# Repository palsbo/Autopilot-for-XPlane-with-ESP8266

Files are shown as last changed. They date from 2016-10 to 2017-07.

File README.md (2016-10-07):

# Autopilot
An ESP8266 based Autopilot for X-Plane
This is a hardware based autopilot to be useed together with X-Plane (tested on X-Plane v10.50).

Hardware:
The printed circuit is developed in Target3001
OBS! read the file 'corrections.txt' before mounting the printed curcuit.

Software:
The software for the ESP8266 is in the Arduino folder together with all required libraries.
(for Arduino IDE)

Project details here: http://palsbo.com/xplane/Autopilot.html 

Files in this GitHup are the newest

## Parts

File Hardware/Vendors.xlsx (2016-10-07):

Conmonent | Value | Description | Vendor URL | prod code
R10 | 7x3K3 | Resistor network | http://dk.rs-online.com/ | 4608x-101-332lf
R11 - R12 | 7x330 | Resistor network | http://dk.rs-online.com/ | 4608x-101-331lf
R8 | 10K | Trim Pot | http://dk.rs-online.com/ | 3362P-1-103LF
C1 - C3 | 100nf | poly cond. | http://dk.rs-online.com/ | bfc236845104
SD1 - SD12 |  | Switch with led | http://www.velleman.eu/products/view/?id=2757 | SP86-B2-5-1
PE1 - PE3 | MC23017 | I2C port expander | https://www.adafruit.com/product/732
Display1 | LCD | 20x4 LCD | https://www.sparkfun.com/products/256
IC2 | ESP8266-01 | WiFi proc. | https://www.sparkfun.com/products/13678
J1 | 5V | powerplug | http://dk.rs-online.com/ | FC68146SP
Box |  | Alubox | http://www.eluxson.se/apparatlador-aluminium/1568-ah-102-sw.html | AH-102/SW

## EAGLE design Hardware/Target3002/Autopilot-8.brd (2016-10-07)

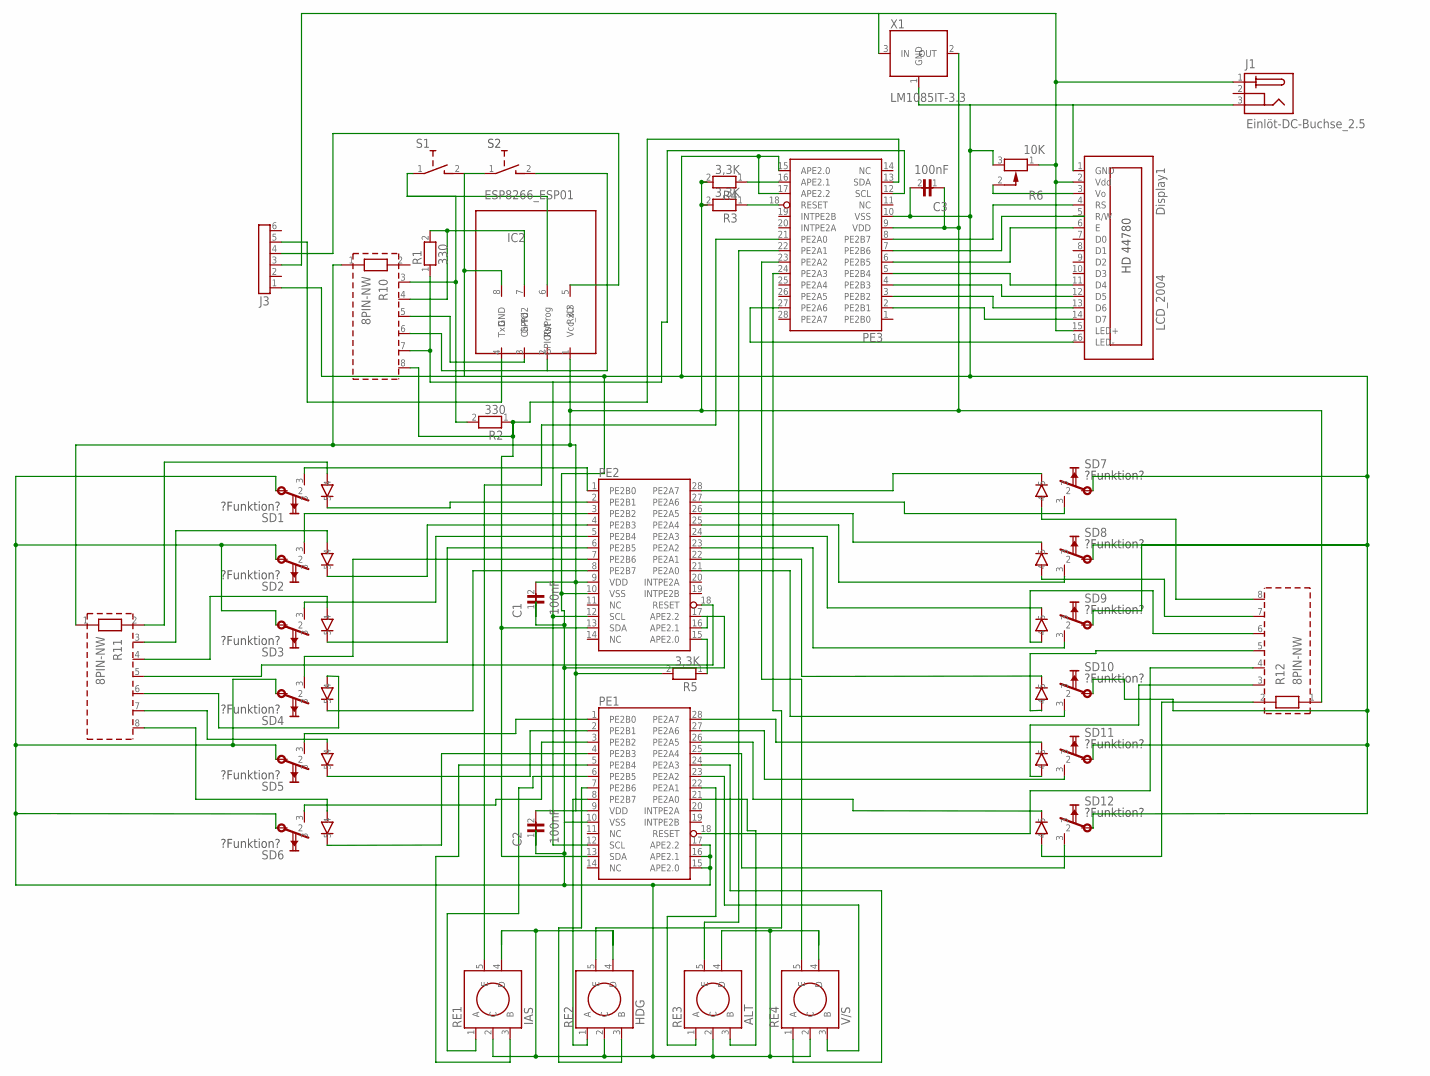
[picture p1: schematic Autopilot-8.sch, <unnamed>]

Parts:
C1: 100nF; 4X13R10,16_11
C2: 100nF; 4X13R10,16_12
C3: 100nF; 4X13R10,16_15
Display1: LCD_2004; LCD2004_13
IC2: ESP8266_ESP01; ESP01_6
J1: Einlöt-DC-Buchse_2.5; EINLÖT-DC-BUCHSE_2.5MM_36
J3: PinHeader_1x06_W_2,54; 1X06-90_32
PE1: PORTEXPANDER MCP23017; PortExpander_Gehäuse:PDIP-28_4
PE2: PORTEXPANDER MCP23017; PortExpander_Gehäuse:PDIP-28_5
PE3: PORTEXPANDER MCP23017; PortExpander_Gehäuse:PDIP-28_14
R1: 330; 0207_7
R2: 330; 0207_8
R3: 3,3K; 0207_17
R4: 3,3K; 0207_18
R5: 3,3K; 0207_19
R6: 10K; POTI_PD84_35
R10: 8PIN-NW; SIL8_16
R11: 8PIN-NW; SIL8_9
R12: 8PIN-NW; SIL8_10
RE1: IAS; STEC12E08_3
RE2: HDG; STEC12E08_2
RE3: ALT; STEC12E08_1
RE4: V/S; STEC12E08_0
S1: PHAP3362A; KURZHUBTASTER_DURCHSTECKMONT._33
S2: PHAP3362A; KURZHUBTASTER_DURCHSTECKMONT._34
SD1: TASTER_DIGITAST_STD-LED-SJS; TASTER_DIGITAST_STD(#1)(#1)_20
SD2: TASTER_DIGITAST_STD-LED-SJS; TASTER_DIGITAST_STD(#1)(#1)_21
SD3: TASTER_DIGITAST_STD-LED-SJS; TASTER_DIGITAST_STD(#1)(#1)_22
SD4: TASTER_DIGITAST_STD-LED-SJS; TASTER_DIGITAST_STD(#1)(#1)_23
SD5: TASTER_DIGITAST_STD-LED-SJS; TASTER_DIGITAST_STD(#1)(#1)_24
SD6: TASTER_DIGITAST_STD-LED-SJS; TASTER_DIGITAST_STD(#1)(#1)_25
SD7: TASTER_DIGITAST_STD-LED-SJS; TASTER_DIGITAST_STD(#1)(#1)_26
SD8: TASTER_DIGITAST_STD-LED-SJS; TASTER_DIGITAST_STD(#1)(#1)_27
SD9: TASTER_DIGITAST_STD-LED-SJS; TASTER_DIGITAST_STD(#1)(#1)_28
SD10: TASTER_DIGITAST_STD-LED-SJS; TASTER_DIGITAST_STD(#1)(#1)_29
SD11: TASTER_DIGITAST_STD-LED-SJS; TASTER_DIGITAST_STD(#1)(#1)_30
SD12: TASTER_DIGITAST_STD-LED-SJS; TASTER_DIGITAST_STD(#1)(#1)_31
X1: LM1085IT-3.3; TO220_37

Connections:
5V: Display1.2 (Vdd), Display1.15 (LED+), J1.1 (S), J3.3, R6.1, X1.3 (IN)
ALT: PE2.23 (PE2A2), SD9.3
AP-AUTO: PE2.5 (PE2B4), SD3.3
AP-OFF: PE2.1 (PE2B0), SD1.3
AP-ON: PE2.3 (PE2B2), SD2.3
APE2.0: PE2.15 (APE2.0), R5.1
ATHR: PE1.1 (PE2B0), SD5.3
B: PE1.23 (PE2A2), RE4.3 (B)
BC: PE1.25 (PE2A4), SD12.3
D4: Display1.11 (D4), PE3.5 (PE2B4)
D6: Display1.13 (D6), PE3.3 (PE2B2)
ESP-RST: IC2.2 (Rst), R10.6, S2.2
FLCH: PE2.7 (PE2B6), SD4.3
GND: C1.1, C2.1, C3.2, Display1.1 (GND), IC2.8 (GND), J1.3 (T), J3.1, PE1.10 (VSS), PE1.15 (APE2.0), PE1.16 (APE2.1), PE1.17 (APE2.2), PE2.10 (VSS), PE2.16 (APE2.1), PE2.17 (APE2.2), PE3.10 (VSS), PE3.15 (APE2.0), PE3.17 (APE2.2), R6.3, RE1.2 (C), RE1.4 (D), RE2.2 (C), RE2.4 (D), RE3.2 (C), RE3.4 (D), RE4.2 (C), RE4.4 (D), S1.2, S2.1, SD1.2, SD2.2, SD3.2, SD4.2, SD5.2, SD6.2, SD7.2, SD8.2, SD9.2, SD10.2, SD11.2, SD12.2, X1.1 (GND)
GPIO0/Prog: IC2.6 (GPIO0/Prog), R2.2, R10.3, S1.1
GPIO2: IC2.7 (GPIO2), R1.2, R10.4
GS: PE2.21 (PE2A0), SD10.3
HDG: PE2.27 (PE2A6), SD7.3
LED-ALT: PE2.24 (PE2A3), SD9.4
LED-AP-AUTP: PE2.6 (PE2B5), SD3.4
LED-AP-OFF: PE2.2 (PE2B1), SD1.4
LED-AP-ON: PE2.4 (PE2B3), SD2.4
LED-ATHR: PE1.2 (PE2B1), SD5.4
LED-BC: PE1.26 (PE2A5), SD12.4
LED-FLCH: PE2.8 (PE2B7), SD4.4
LED-GS: PE2.22 (PE2A1), SD10.4
LED-HDG: PE2.28 (PE2A7), SD7.4
LED-LOC: PE1.4 (PE2B3), SD6.4
LED-VNAV: PE2.26 (PE2A5), SD8.4
LED-VS: PE1.28 (PE2A7), SD11.4
LOC: PE1.3 (PE2B2), SD6.3
PE2A1: PE1.22 (PE2A1), RE3.1 (A)
PE2B4: PE1.5 (PE2B4), RE1.3 (B)
PE2B5: Display1.12 (D5), PE3.4 (PE2B3)
PE2B6: PE1.7 (PE2B6), RE2.3 (B)
R/W: Display1.5 (R/W), PE3.7 (PE2B6)
RESET: PE1.18 (RESET), R12.4
RS: Display1.4 (RS), PE3.8 (PE2B7)
SCL: PE1.12 (SCL), PE2.12 (SCL), PE3.12 (SCL), R1.1, R10.7
SDA: PE1.13 (SDA), PE2.13 (SDA), PE3.13 (SDA), R2.1, R10.8
Sig$24: PE1.21 (PE2A0), RE3.3 (B)
Sig$27: PE1.8 (PE2B7), RE2.1 (A)
Sig$29: PE1.6 (PE2B5), RE1.1 (A)
Sig$107: R12.2, SD12.5
Sig$108: R12.7, SD8.5
Sig$118: IC2.3 (Ch-Pd), R10.5
Sig$129: R12.3, SD11.5
Sig$131: R12.6, SD9.5
Sig$132: R12.8, SD7.5
Sig$137: R11.2, SD1.5
Sig$138: R11.3, SD2.5
Sig$139: R11.4, SD3.5
Sig$140: PE2.18 (RESET), R11.5
Sig$141: R11.6, SD4.5
Sig$142: R11.7, SD5.5
Sig$143: R11.8, SD6.5
Sig$195: Display1.14 (D7), PE3.2 (PE2B1)
Sig$208: Display1.6 (E), PE3.6 (PE2B5)
Sig$209: PE3.18 (RESET), R3.1
Sig$211: PE3.16 (APE2.1), R4.1
Sig$230: R12.5, SD10.5
Sig$260: Display1.16 (LED-), PE3.27 (PE2A6)
Sig$269: IC2.5 (RxD), J3.4
TxD: IC2.4 (TxD), J3.5
VCC3.3: C1.2, C2.2, C3.1, IC2.1 (Vcc_3.3), PE1.9 (VDD), PE2.9 (VDD), PE3.9 (VDD), R3.2, R4.2, R5.2, R10.1, R11.1, R12.1, X1.2 (OUT)
VNAV: PE2.25 (PE2A4), SD8.3
VS: PE1.27 (PE2A6), SD11.3
Vo: Display1.3 (Vo), R6.2
ss0: PE3.21 (PE2A0), RE1.5 (E)
ss1: PE3.22 (PE2A1), RE3.5 (E)
ss2: PE3.23 (PE2A2), RE4.5 (E)
ss3: PE3.24 (PE2A3), RE2.5 (E)
xx: PE1.24 (PE2A3), RE4.1 (A)

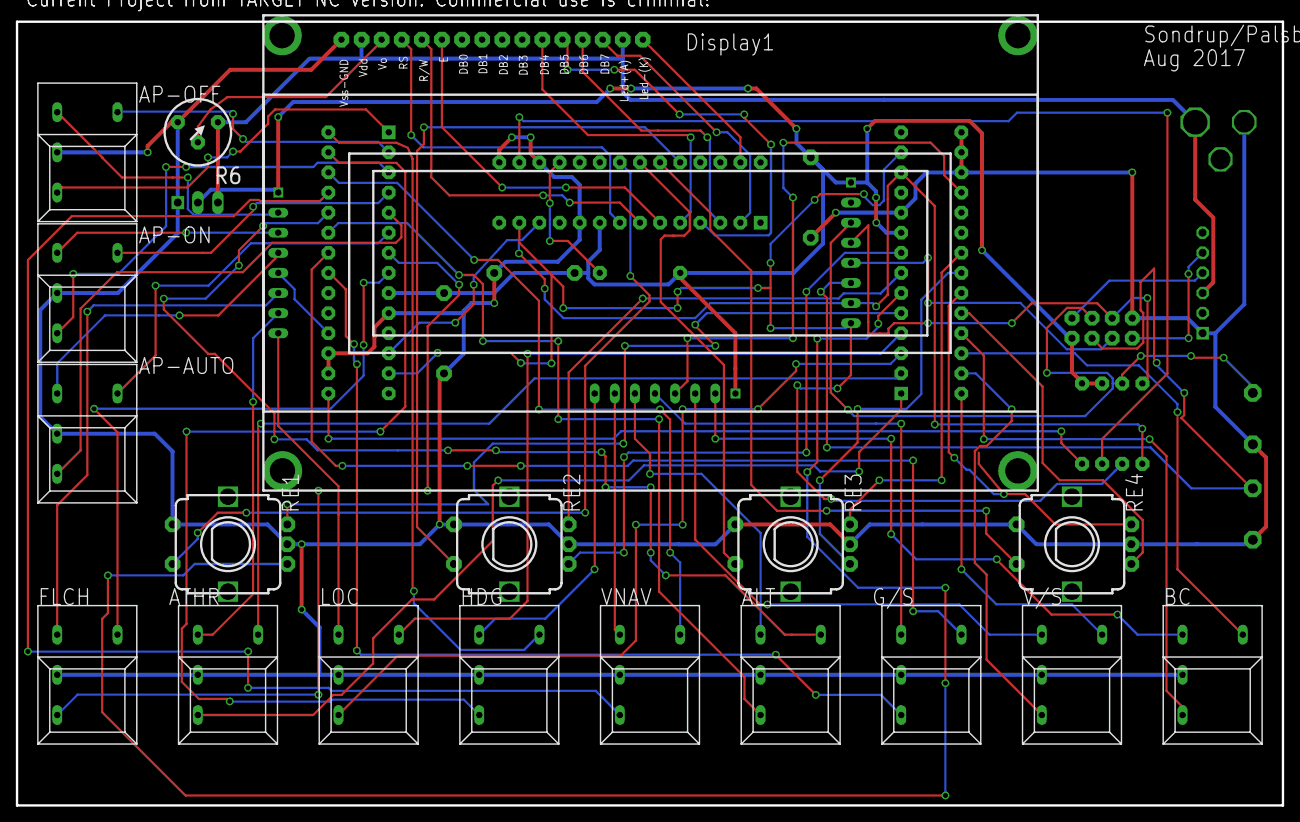
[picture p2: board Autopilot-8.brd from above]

Board: 2 copper layers, 160.0 x 99.1 mm, 38 parts (0 on the bottom side), 73 nets.

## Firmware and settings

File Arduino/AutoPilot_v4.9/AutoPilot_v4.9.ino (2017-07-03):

/*
 * ----------------------------------------------------------
 * The Autopilot project
 * by erik@palsbo.com
 * http://palsbo.com/xplane/Autopilot.html
 * ----------------------------------------------------------
*/
#include <ESP8266WiFi.h>
#include <DNSServer.h>
#include <WiFiManager.h>         //https://github.com/tzapu/WiFiManager
#include <ArduinoOTA.h>          //For OTA
#include "lcd.h"
#include "xplane.h"
#include "autopilot.h"

#define FIXEDSSID false  //  set true for fixed SSID configuration
#define STATICIP true    //  set true to use static IP for autopilot
#define XPIP false       //  set true for hardcoding of XPlane IP

#if FIXEDSSID
char ssid[] = ".....";   //  set to SSID for predefined WiFi network
char pass[] = ".....";   //  set to password for predefined WiFi network
#endif

#if STATICIP              //  details for static IP
IPAddress _ip = IPAddress(192, 168, 1, 20);
IPAddress _gw = IPAddress(192, 168, 1, 1);
IPAddress _sn = IPAddress(255, 255, 255, 0);
#endif

#if XPIP                  //  details for predefined X Plane IP
IPAddress xp_ip = IPAddress(192, 168, 1, 68);
#endif

// ----------------------------------------------------------

#define APNAME "AutopilotAP"
String file = __FILE__;
unsigned long butTimer;

enum CONMODE {
  isAP,
  isConnecting,
  isConnected,
  isWaiting,
  isOnline
} conMode;

void showConMode(CONMODE mode) {
  lcd.clear();
  switch (mode) {
    case isAP:
      lcd.print(0, 0, "WiFi Access point:  ");
      lcd.print(0, 1, APNAME);
      lcd.print(0, 2, "IP address: ");
      lcd.print(0, 3, "192.168.4.1");
      break;
    case isConnecting:
      lcd.print(3, 1, "WiFi connecting");
      break;
    case isConnected:
      lcd.print(0, 0, "WiFi connected to:  ");
      lcd.print(0, 1, WiFi.SSID());
      lcd.print(0, 2, "IP address: ");
      lcd.print(0, 3, WiFi.localIP());
      break;
    case isWaiting:
      lcd.print(0, 0, "Waiting for X Plane ");
      lcd.print(0, 1, "                    ");
      lcd.print(0, 2, file.substring(file.lastIndexOf("\\") + 1));
      lcd.print(0, 3, __DATE__ );
      lcd.print(12, 3, __TIME__);
      break;
    case isOnline:
      lcd.print(0, 0, " IAS HDG  ALT   V/S");
      break;
  }
}

void configModeCallback (WiFiManager *myWiFiManager) {
  showConMode(isAP);
}

void setup() {
  Wire.begin();
  Wire.pins(0, 2);
  mcp2.begin(2);      // addr 0x22
  mcp0.begin(0);      // addr 0x20
  mcp1.begin(1);      // addr 0x21
  lcd.begin(20, 4);
  showConMode(isConnecting);
  Serial.begin(115200);
  WiFiManager wifiManager;
#if STATICIP
  wifiManager.setSTAStaticIPConfig(_ip, _gw, _sn);
#endif
  //wifiManager.resetSettings();    //  for resetting saved SSID and Password
  wifiManager.setAPCallback(configModeCallback);
#if FIXEDSSID
  WiFi.begin(ssid, pass);
#else
  wifiManager.autoConnect(APNAME);
#endif
  ArduinoOTA.begin();
  showConMode(isConnected);
  delay(3000);      //  show ip-address
  xplane.onStatusChanged([](bool status) {
    leds.init();
    switch (status) {
      case true:
        showConMode(isOnline);
        autopilotOpen();
        break;
      default:
        showConMode(isWaiting);
        autopilotClose();
        break;
    }
  });
  autopilotInit();
  xplane.begin();
  Wire.setClock(1700000L);
  Wire.setClockStretchLimit(1500);    // in µs
}

void loop() {
  ArduinoOTA.handle();
  if (xplane.scan()) checkFdMode();
  else autopilotCheck();
  delay(1);
}

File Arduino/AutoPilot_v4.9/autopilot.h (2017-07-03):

#ifndef AUTOPILOT_H
#define AUTOPILOT_H
/*
   Functions and commands for Autopilot objects
*/
#include "utils.h"
#include "lcd.h"
#include "xplane.h"
#include "fields.h"
#include "switches.h"

enum DISPMODE {
  
};

#define ISMACH !FldIsMach.isNull()

//  Buttons
BUTTON butMode;
BUTTON butON;
BUTTON butAUTO;
BUTTON butFLCH;
BUTTON butATHR;
BUTTON butLOC;
BUTTON butHDG;
BUTTON butVNAV;
BUTTON butALT;
BUTTON butGs;
BUTTON butVs;
BUTTON butBc;
//  encoder switches
BUTTON EncIAStop;
BUTTON EncHDGtop;
BUTTON EncALTtop;
BUTTON EncVStop;
//  Fields
RFIELD FldIsMach("sim/cockpit2/autopilot/airspeed_is_mach[0]");
RFIELD FldVnav("sim/cockpit2/autopilot/fms_vnav");
RFIELD FldVde("sim/cockpit/radios/nav1_vdef_dot");
RFIELD FldHde("sim/cockpit/radios/nav1_hdef_dot");
//RFIELD FldGsArmed("sim/cockpit2/autopilot/glideslope_status");  //  0=off,1=armed,2=captured
//RFIELD FldHnavArmed("sim/cockpit2/autopilot/vnav_status");    //  0=off,1=armed,2=captured
//RFIELD FldGsOk("sim/cockpit/radios/nav1_CDI");  //  int n bool  Are we receiving an expected glide slope for nav1
RFIELD FldHorOk("sim/cockpit2/radios/indicators/nav1_display_horizontal");  //  int n boolean Is there some kind of horizontal signal on nav1
RFIELD FldVerOk("sim/cockpit2/radios/indicators/nav1_display_vertical");  //  int n boolean Is there some kind of vertical signal on nav1
DFIELD FldActMach(4, 0);
DFIELD FldActIas(3, 0);
DFIELD FldActTas(3, 2);
DFIELD FldActGs(3, 3);
DFIELD FldActVs(4, 2);
DFIELD FldFlaps(13, 3);
DFIELD FldGear(14, 0);
DFIELD FldBreaks(14, 1);
DFIELD FldActHdg(17, 3);
DFIELD FldActAlt(20, 5);
DFIELD FldNav1(97, 0);
DFIELD FldNav2(97, 4);
DFIELD FldDme1(99, 4);
DFIELD FldDme2(100, 4);
DFIELD FldNavSel(107, 3);
DFIELD FldModeFdir(108, 1);
DFIELD FldArmNav(116, 0);
DFIELD FldArmAlt(116, 1);
DFIELD FldArmApp(116, 2);
DFIELD FldArmVnav(116, 3);
DFIELD FldModeAthr(117, 0);
DFIELD FldModeHdg(117, 1);
DFIELD FldModeAlt(117, 2);
DFIELD FldIas(118, 0);
DFIELD FldHdg(118, 1);
DFIELD FldAlt(118, 3);
DFIELD FldVs(118, 2);
//  for KML server
DFIELD GpsLat(20, 0);
DFIELD GpsLon(20, 1);
DFIELD FldPitch(17, 0);
DFIELD FldRoll(17, 1);

//  Encoders
ENCODER encIas;
ENCODER encHdg;
ENCODER encAlt;
ENCODER encVs;
//  Leds
LED ledMode;
LED ledOn;
LED ledAuto;
LED ledFlch;
LED ledAthr;
LED ledLoc;
LED ledHdg;
LED ledVnav;
LED ledAlt;
LED ledGs;
LED ledVs;
LED ledBc;

//-------------------

uint8_t dispMode = 0;
char buf[22];
long factor;
int cnt;

//enum IASMODE { IAS, MACH } iasMode = IAS;
//bool autoThrottle;

void initActValues() {
  FldActIas.init();
  FldActHdg.init();
  FldActAlt.init();
  FldActVs.init();
}

void initApValues() {
  FldIas.init();
  FldHdg.init();
  FldAlt.init();
  FldVs.init();
}

void initSpeedValues() {
  FldActIas.init();
  lcd.print(0, 2, " IAS TAS   GS  MACH ");
}

void initBreakingValues() {
  FldFlaps.init();
  FldGear.init();
  FldBreaks.init();
}

void autopilotOpen() {
  xplane.onRREF([](long idx, float val) {
    if (idx < rfieldlist.count) {
      rfieldlist.list[idx]->value = val;
    }
    return false;
  });
  FldModeFdir.init();
  FldModeAthr.init();
  FldModeHdg.init();
  FldArmNav.init();
  FldModeAlt.init();
  FldArmAlt.init();
  FldArmApp.init();
  FldGear.init();
  FldFlaps.init();
  FldBreaks.init();

  ledMode.value(0);
  ledOn.value(0);
  ledAuto.value(0);
  ledFlch.value(0);
  ledAthr.value(0);
  ledLoc.value(0);
  ledHdg.value(0);
  ledVnav.value(0);
  ledAlt.value(0);
  ledVs.value(0);
  ledGs.value(0);
  ledBc.value(0);
  initApValues();
  initActValues();
  initSpeedValues();
}

void autopilotClose() {
  dispMode = 0;
}

void autopilotInit() {
  //  init buttons
  butMode.begin(8, mcp1);
  butON.begin(10, mcp1);
  butAUTO.begin(12, mcp1);
  butFLCH.begin(14, mcp1);
  butATHR.begin(8, mcp0);
  butLOC.begin(10, mcp0);
  butALT.begin(2, mcp1);
  butGs.begin(0, mcp1);
  butHDG.begin(6, mcp1);
  butVNAV.begin(4, mcp1);
  butVs.begin(6, mcp0);
  butBc.begin(4, mcp0);
  //  init LEDs
  ledMode.begin(9, mcp1);
  ledOn.begin(11, mcp1);
  ledAuto.begin(13, mcp1);
  ledFlch.begin(15, mcp1);
  ledAthr.begin(9, mcp0);
  ledLoc.begin(11, mcp0);
  ledAlt.begin(3, mcp1);
  ledGs.begin(1, mcp1);
  ledHdg.begin(7, mcp1);
  ledVnav.begin(5, mcp1);
  ledVs.begin(7, mcp0);
  ledBc.begin(5, mcp0);
  //  init encoders
  encIas.begin(13, 12, mcp0, 1, 16);
  encHdg.begin(15, 14, mcp0, 1, 8);
  encAlt.begin(1, 0, mcp0, 100, 800);
  encVs.begin(3, 2, mcp0, 100, 200);
  //  init switch on encoders
  EncIAStop.begin(0, mcp2);
  EncHDGtop.begin(3, mcp2);
  EncALTtop.begin(1, mcp2);
  EncVStop.begin(2, mcp2);
}

void showActValues(uint8_t line) {
  if (FldActIas.changed() || FldActMach.changed() || FldIsMach.changed()) {
    if (ISMACH) lcd.printf(0, line, "%4s", FldActMach.adjust(4, true).c_str());
    else lcd.printf(0, line, "%4s", FldActIas.adjust(4, false).c_str());
  }
  if (FldActHdg.changed()) {
    lcd.print(5, line, "%03d", (long)round(FldActHdg.get()));
  }
  if (FldActAlt.changed()) {
    lcd.print(9, line, "%5d", (long) round(FldActAlt.get()));
  }
  if (FldActVs.changed()) {
    if (round(FldActVs.get()) == 0) lcd.print(15, line, "     ");
    else lcd.print(15, line, "%5d", (long) round(FldActVs.get()));
  }
}

void showApValues() {
  if (gs.changed(FldVde.get(), FldHde.get(), FldVerOk.get(), FldHorOk.get())) {
    lcd.print(14, 0, gs.pointer);
  }
  if (FldIsMach.changed()) {
    lcd.print(0, 0, (ISMACH ? "MACH" : " IAS"));
    lcd.printf(0, 1, "%4s", FldIas.adjust(4, ISMACH).c_str());
    if (FldModeFdir.get() == 1) lcd.printf(0, 1, "%4s", FldActIas.adjust(4, ISMACH).c_str());
  }
  if (FldIas.changed(ISMACH ? 3 : 0)) {
    lcd.printf(0, 1, "%4s", FldIas.adjust(4, ISMACH).c_str());
  }
  if (FldHdg.changed()) {
    lcd.print(5, 1, "%03d", (long(round(FldHdg.get()))));
  }
  if (FldAlt.changed()) {
    lcd.print(9, 1, "%5d", (long)round(FldAlt.get()));
  }
  if (FldVs.changed()) {
    int val = round(FldVs.get());
    if (val == 0) lcd.print(15, 1, "     ");
    else lcd.print(15, 1, "%5d", val);
  }
}

void showSpeedValues() {
  if (xplane.online) {
    if (FldActIas.changed()) {
      //float tas = FldActTas.get()*1.94384449244;
      lcd.printf(0, 3, "%4d", round(FldActIas.get()));
      lcd.printf(4, 3, "%4d", round(FldActTas.get()));
      lcd.printf(9, 3, "%4d", round(FldActGs.get()));
      lcd.printf(15, 3, "%4s", FldActMach.adjust(4, true).c_str());
    }
  }
}

void showBreakingValues(uint8_t line) {        //  Show Flaps, Gear, Breaks in Line 3
  if (FldFlaps.changed(3)) {
    lcd.print(0, line, "F:%3d\%", (uint8_t)(FldFlaps.get() * 100));
  }
  if (FldGear.changed()) {
    sprintf(buf, "G:%3s", (uint8_t)FldGear.get() == 1 ? "DWN" : " UP");
    lcd.print(7, line, buf);
  }
  if (FldBreaks.changed()) {
    sprintf(buf, "B:%3s", FldBreaks.get() == 0 ? "OFF" : " ON");
    lcd.print(13, line, buf);
  }
}
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

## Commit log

2016-10-07 modified: README.md deleted: Target3002/Autopilot-8.T3001 deleted: Target3002/Autopilot-8.brd deleted: Target3002/Autopilot-8.sch deleted: Target3002/XGerber/Autopilot-8.Apr deleted: Target3002/XGerb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
    [Autopilot-8.brd, Autopilot-8.sch]
2016-10-07 First Upload
    [Autopilot-8.brd, Autopilot-8.sch, Vendors.xlsx]
